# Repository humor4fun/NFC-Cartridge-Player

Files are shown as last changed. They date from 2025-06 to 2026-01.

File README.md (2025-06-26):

 # 🎞️ ESP Home Cartridge Player

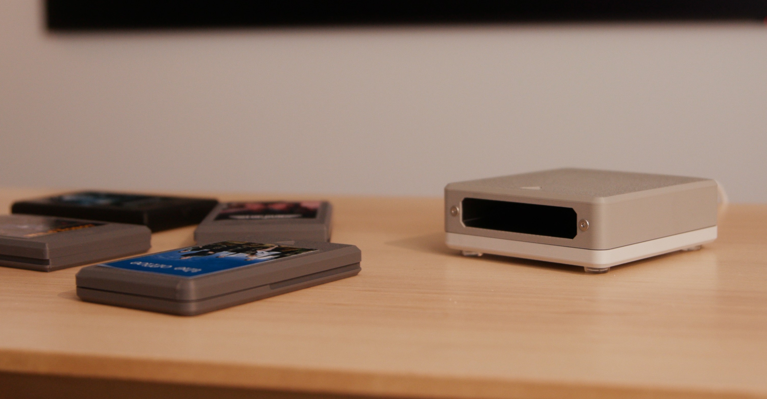
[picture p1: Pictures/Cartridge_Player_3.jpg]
Cartridge Player


Bring back the magic of movie night — without the rewinding.

This ESPHome-powered cartridge player uses NFC tags and Home Assistant to recreate the nostalgia of physical media. Insert a cartridge, and your smart home takes care of the rest: turning on the TV, playing a movie, dimming the lights — whatever you like.

Whether you're a fan of VHS-era rituals or just want a fun new way to launch automations, this project combines retro vibes with modern convenience.

---

## 🔗 Quick Links

- 🔽 **[Latest Release](https://github.com/TheStockPot/NFC-Cartridge-Player/releases/latest)**  
- 📖 **[Blog Post](https://www.thestockpot.net/videos/cartrdgeplayer)**  
- 📦 **[Bill of Materials](https://github.com/TheStockPot/NFC-Cartridge-Player/blob/TheStockPot-VideoRelease/BOM.md)**  
- 🖨️ **[3D Print Files](https://www.printables.com/model/1337649-esphome-cartridge-player)**  
- 🧠 **[ESPHome Config](https://github.com/TheStockPot/NFC-Cartridge-Player/blob/TheStockPot-VideoRelease/esphome/cartridge_player.yaml)**  
- 📺 **[Project Video](https://www.youtube.com/@TheStockPot-AU)**  
- 🛠️ **[Assembly & Automation Tutorial](https://www.youtube.com/@TheSaucepan-AU)**

---

## 🧰 What It Does

- Reads NFC tags inside custom 3D-printed cartridges  
- Sends tag ID to Home Assistant via ESPHome  
- Triggers automations like:
  - Playing a specific movie or playlist (e.g. via Plex or YouTube)
  - Turning on devices or scenes
  - Running scripts (e.g. dimming lights, launching consoles)

---

## 🛠️ Build Your Own

All components are simple and affordable, with a [Bill of Materials available here](https://github.com/TheStockPot/NFC-Cartridge-Player/blob/TheStockPot-VideoRelease/BOM.md), and a full kit available at [thestockpot.net](https://www.thestockpot.net).

🛠️ **Assembly & programming tutorial:**  
[▶️ Watch the tutorial video](https://www.youtube.com/@TheSaucepan-AU)

---

## 🧑‍💻 How It Works

1. Insert a cartridge  
2. ESP32 detects the NFC tag via the RC522  
3. ESPHome reports the tag ID to Home Assistant  
4. Home Assistant runs an automation based on the cartridge ID  
5. Cartridge removed? Media stops. Magic.

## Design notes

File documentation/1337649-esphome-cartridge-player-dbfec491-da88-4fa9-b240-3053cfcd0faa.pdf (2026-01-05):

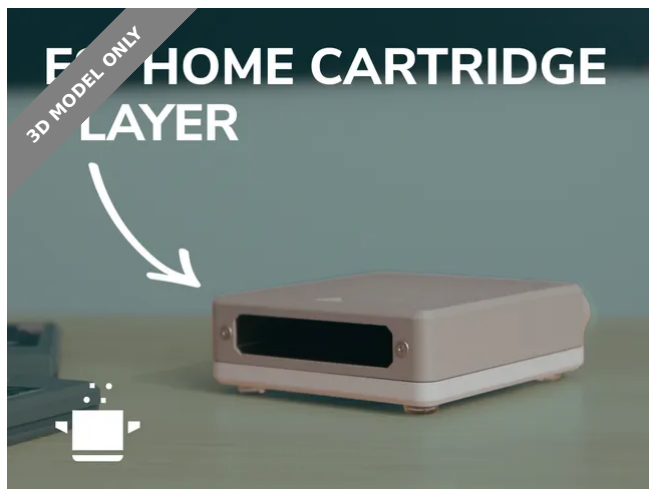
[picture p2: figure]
3D MODEL ONLY

## Summary

A little ESPHome device to stoke my physical media nostalgia!

Gadgets (https://printables.com/model?categoryId=21) > Other Gadgets (https://printables.com/model?categoryId=43)

Tags: | esp32 | homeassistant

Bring back the magic of movie night — without the rewinding.

This NFC-powered media player uses 3D-printed cartridges and ESPHome to trigger movies, playlists, or automations in Home Assistant. Just insert a cartridge, and your smart home takes care of the rest.

UPDATES 18/07/2025

Cartridge Player_Bottom_Buzzer added for use with the buzzer included in the parts kit from our website Cartridge_Top_RecessedLabel added for recessed labels (requires support) - Inspired by Bas van der Ploeg @bvdp
Clearance for cartridges slightly increased for pocket and Player_Top components

BUY A PARTS KIT HERE (https://www.thestockpot.net/store/p/cartridge-player) Links

Blog post & build guide (https://www.thestockpot.net/videos/cartrdgeplayer)

The Stock Pot (https://printables.com/@TheStockPot)

## ESPHome Cartridge Player

VIEW IN BROWSER (https://printables.com/model/1337649-esphome-cartridge-player)

updated 18. 7. 2025 | published 18. 7. 2025

•

•

•

•

GitHub repo (firmware, wiring, YAML) (https://github.com/TheStockPot/NFC-Cartridge-Player) ESPHome config (https://github.com/TheStockPot/NFC-Cartridge-Player/blob/main/YAML/ESPHome%20V1.0.2)
Bill of Materials (https://github.com/TheStockPot/NFC-Cartridge-Player/blob/main/BOM.md)
Parts kit

Features

NFC cartridge-based ESP Home device
Works with ESP32, RC522, and Home Assistant Automates anything — movies, music, lighting, games Easy to print and put together

Tutorial Video What You’ll Need

ESP32-S3 Zero
RC522 NFC module
NFC stickers (one per cartridge) Hardware
Optional: buzzer for sound feedback

Full BOM, firmware, and config available here (https://github.com/TheStockPot/NFC-Cartridge-Player)

Print Instructions

All parts should be oriented correctly when you import them into your slicer. Pictured player was printed in Bambulab Light Gray (10104) & Gray (10103)
Filament choice shouldn't matter. I've tested PETG, ABS and PLA without issue.

Cartridges:

Print with outside faces on the print bed
No supports required
Insert NFC tag before snapping halves together

There are cutting and printing templates below for printing your own labels.

Player Housing:

Use painted supports for the latch on the ‘Cartridge Player_Pocket’ component, and on the cartridge opening on the ‘Cartridge Player_Top’ component.
Avoid auto supports (bridging is intentional)

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
## Model files

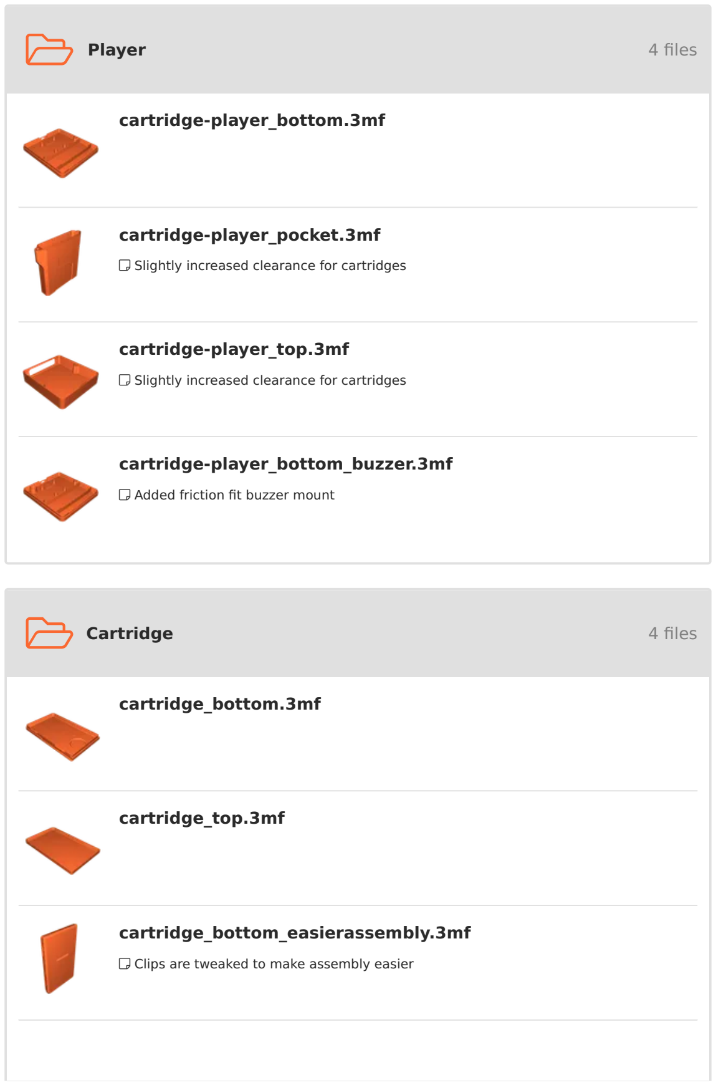
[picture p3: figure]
Player; 4 files; Added friction fit buzzer mount; Cartridge; cartridge-player_bottom.3mf; cartridge-player_pocket.3mf; cartridge-player_top.3mf; cartridge-player_bottom_buzzer.3mf; cartridge_bottom.3mf; cartridge_top.3mf; cartridge_bottom_easierassembly.3mf

- Slightly increased clearance for cartridges
- Slightly increased clearance for cartridges
- Clips are tweaked to make assembly easier

## Other files

- Label is recessed - requires support (Inspired by Bas van der Ploeg @bvdp)
- Cartridge sticker cutting template
- Cartridge sticker pdf template

## License

This work is licensed under a
Creative Commons (4.0 International License)

Attribution-NonCommercial (http://creativecommons.org/licenses/by-nc/4.0/)

✖ | Sharing without ATTRIBUTION
✔ | Remix Culture allowed
✖ | Commercial Use
✖ | Free Cultural Works
✖ | Meets Open Definition

cartridge_top_recessedlabel.3mf

sticker_template.dxf

sticker_template.pdf

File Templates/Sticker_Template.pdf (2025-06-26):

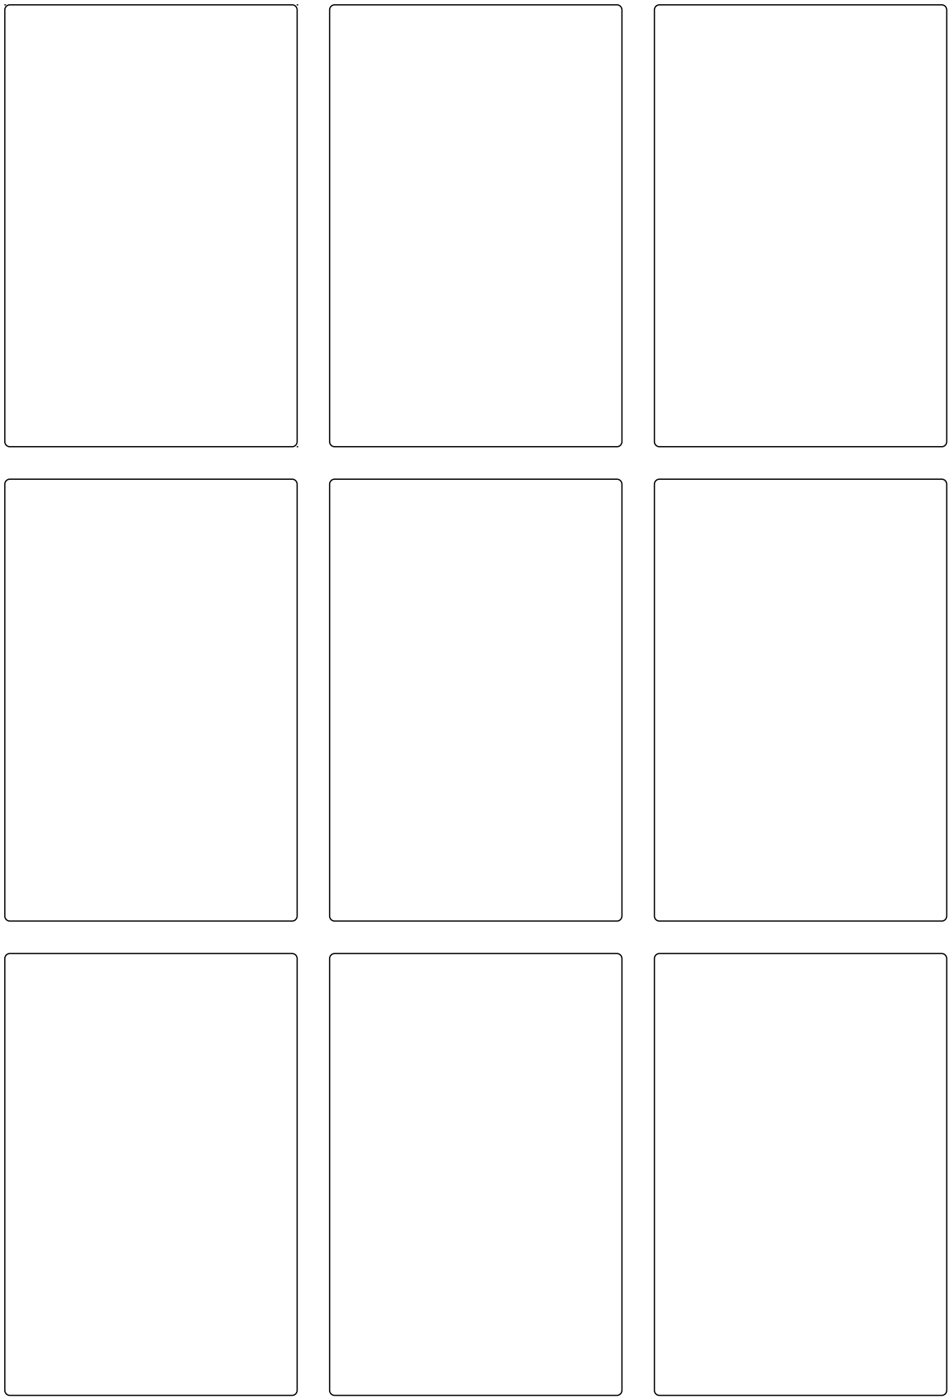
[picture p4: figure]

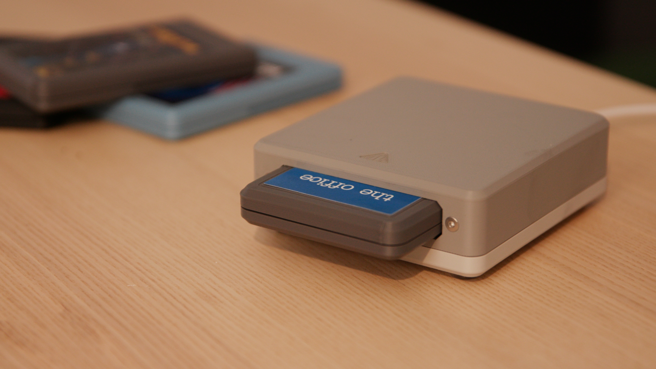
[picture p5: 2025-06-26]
Pictures/Cartridge_Player_2.jpg

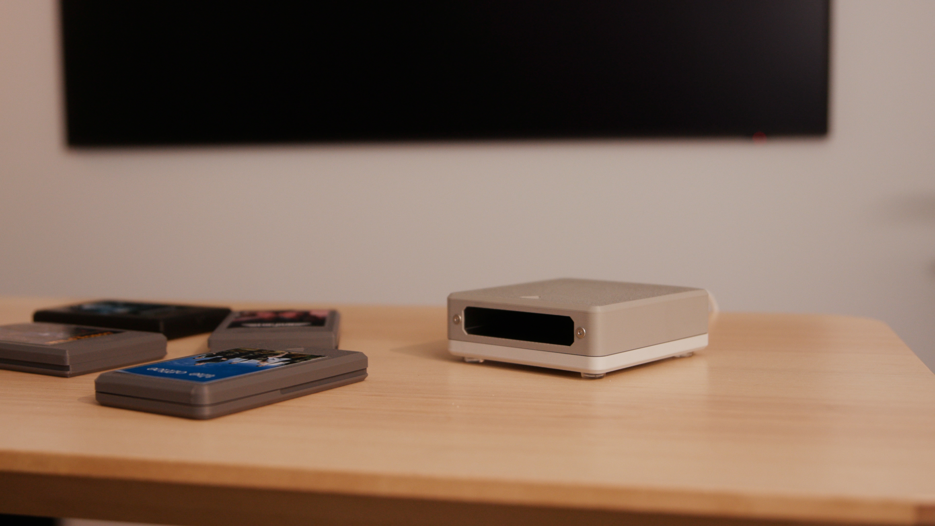
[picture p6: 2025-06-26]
Pictures/Cartridge_Player_1.jpg

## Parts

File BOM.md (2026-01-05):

# NFC Cartridge Player – Bill of Materials

Everything you need to build **The NFC Cartridge Player**.

---

## Components

| Item | Qty | Source | Notes |
|---|-----|---|---|
| ESP32-C3 Zero Dev board | 1 | [Waveshare](https://www.waveshare.com/esp32-c3-zero.html) | You can get these elswhere cheaper sometimes, the S3 model also works (use the S3 binary file) |
| RC522 RFID dev board | 1 | [Digikey](https://www.digikey.com.au/en/products/detail/sunfounder/CN0090/18668629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) | You can also get these elswhere for less. Just make sure the hole positions look the same. |
| Buzzer | 1 (optional) | [Amazon AU](https://www.amazon.com.au/QMseller-Active-Industrial-Electric-Alarmer/dp/B08G518BHN) | These are most similar to mine. They cannot be any wider than these. Smaller is fine. |
| 25mm NFC Stickers | 1 for each cartridge | [Amazon AU](https://www.amazon.com.au/50PCS-Ntag215-Enabled-Phones-Compatible/dp/B099X5TZPW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) | Almost any type will work |
| Double-sided mounting tape | 1 | | Any general-purpose double-sided tape will do. |
| Hookup Wire | 1 | | Hookup wire - 6 x 50mm lengths |
| M3 x 10mm countersunk machine screws  | 2 |  | Part of M2 screw assortments — handy to have. |
| M3 x 10mm cap head screws (pan head is ok too)  | 4 |  | Also from typical M2 screw kits. |
| 10-13mm rubber feet  | 4 |  | Standard rubber furniture feet. Available at hardware stores / online |

Alternative links and components
| Alternate | qty | Replaces what? | Source | Notes |
|---|-----|---|---|---|
| ESP32-C3 SuperMini dev board | 1 | esp32-c3 zero | [Amazon USA](https://www.amazon.com/dp/B0D47G24W3) | |
| Mifare RC522 Reader | 1 | RC522 | [Amazon USA](https://www.amazon.com/dp/B09P5WJWLN) | |
| Buzzer | 1 | Buzzer | [Amazon USA](https://www.amazon.com/dp/B0FNMH6QH8) | Note: this will NOT fit the buzzer 3dprinted buzzer holder, but will fit inside the shell if stood on its side. |
| ESP32-S3 Mini Dev Board | 1 | esp32-c3 zero | [Amazon USA](https://www.amazon.com/dp/B0CHYHGYRH) | |
| NFC Sticker | 1/cart | NFC Sticker | [Amazon USA](https://www.amazon.com/dp/B0F24L4GDM) | |
---

## 3D Prints

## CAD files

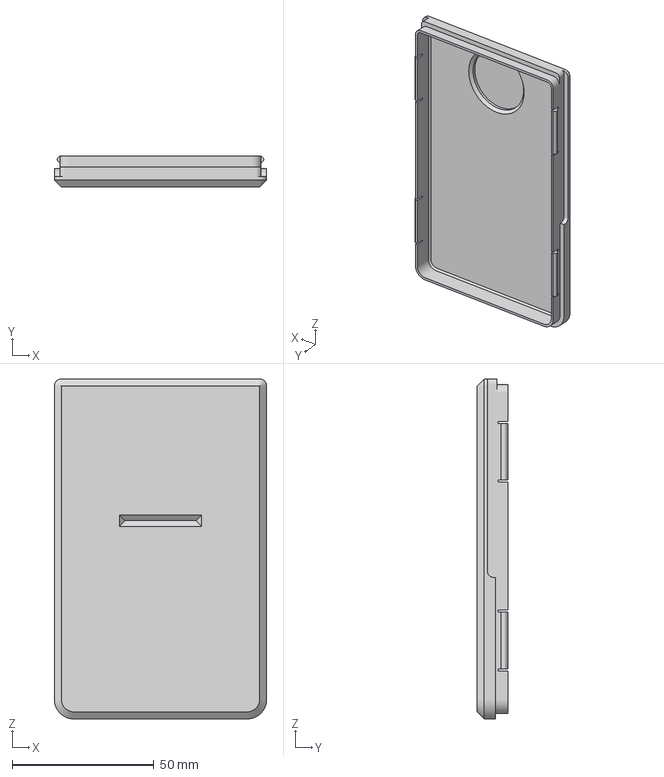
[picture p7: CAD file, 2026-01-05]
3d print files/Cartridge/cartridge_bottom_easierassembly.3mf
75.0 x 11.0 x 120.0 mm

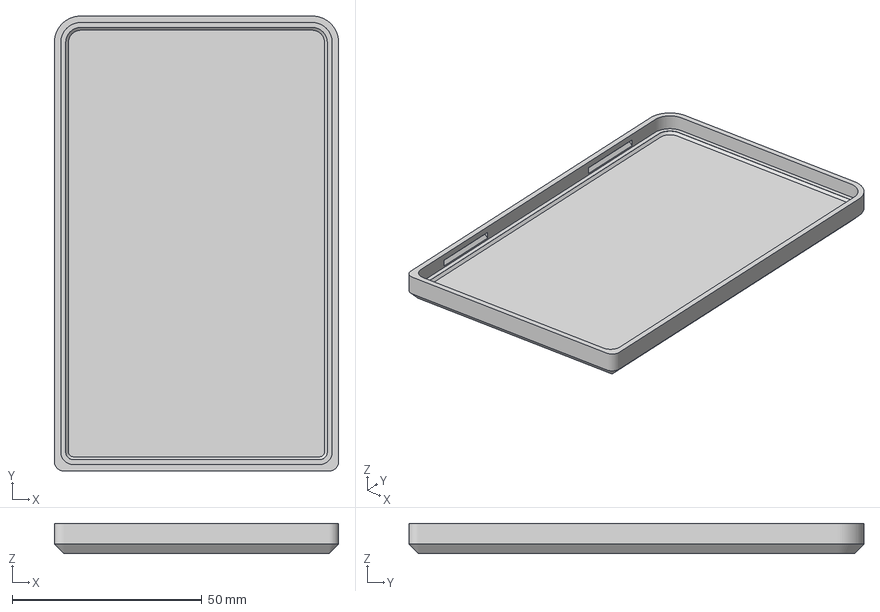
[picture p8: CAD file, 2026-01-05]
3d print files/Cartridge/cartridge_top.3mf
75.0 x 120.0 x 8.00 mm

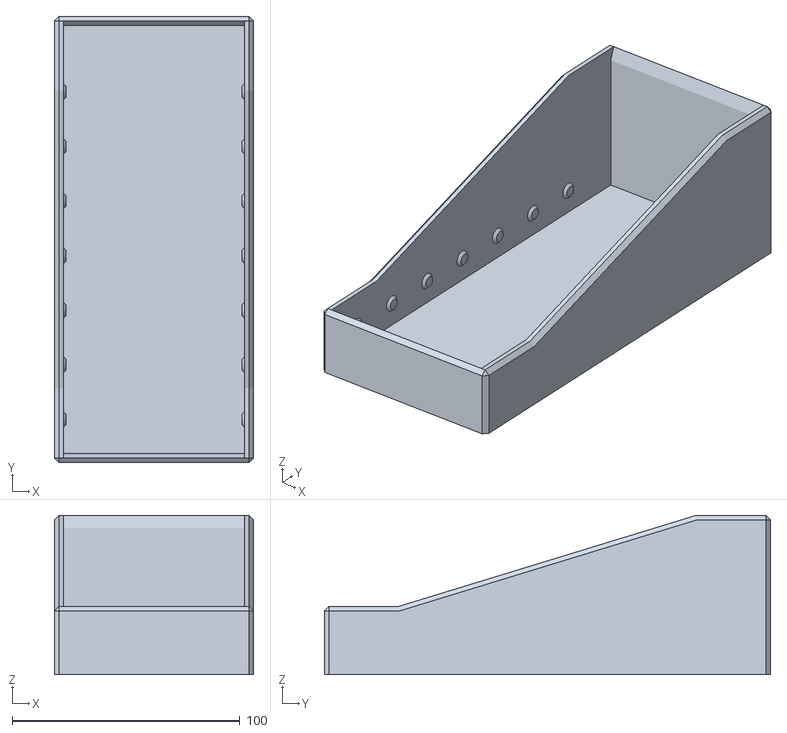
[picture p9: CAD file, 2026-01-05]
3d print files/Flip cartridge box/Box/cartridge-box-7-slot.stl
87.6 x 196.0 x 70.0

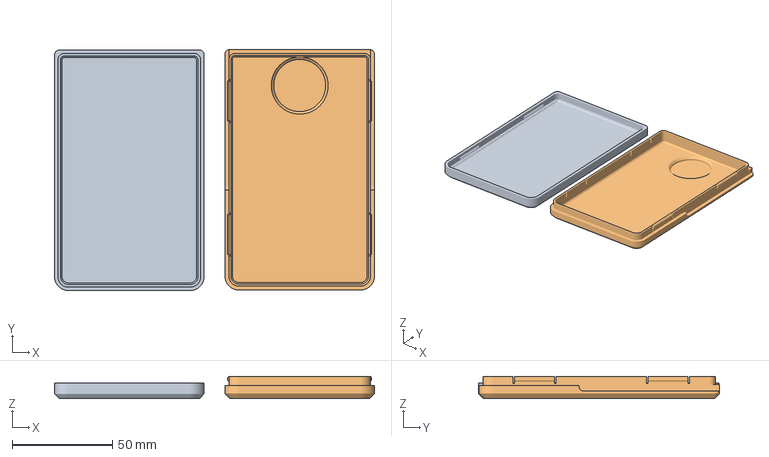
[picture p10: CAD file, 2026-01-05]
3d print files/Flip cartridge box/Cartridge/Cartridge+Modified+(Multicolor).3mf
159.6 x 120.2 x 11.0 mm
Top Case
Bottom Case

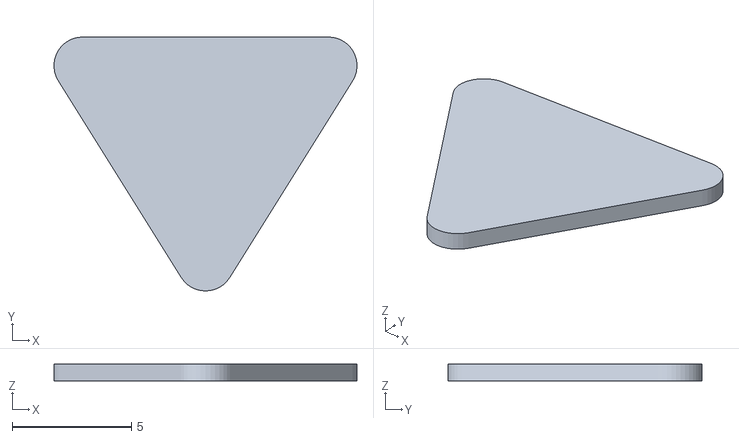
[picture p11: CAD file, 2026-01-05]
3d print files/mods/arrow insert/Triangle 0.1mm offset smaller.stl
12.7 x 10.6 x 0.7

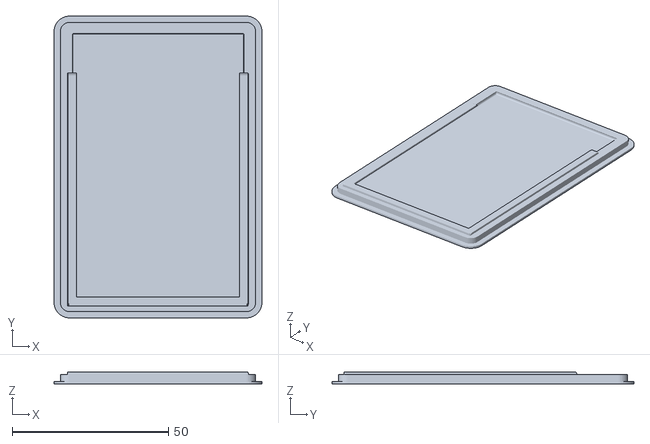
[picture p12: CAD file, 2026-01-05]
3d print files/mods/Cartridge-Card-Pouch.stl
66.5 x 96.5 x 3.80

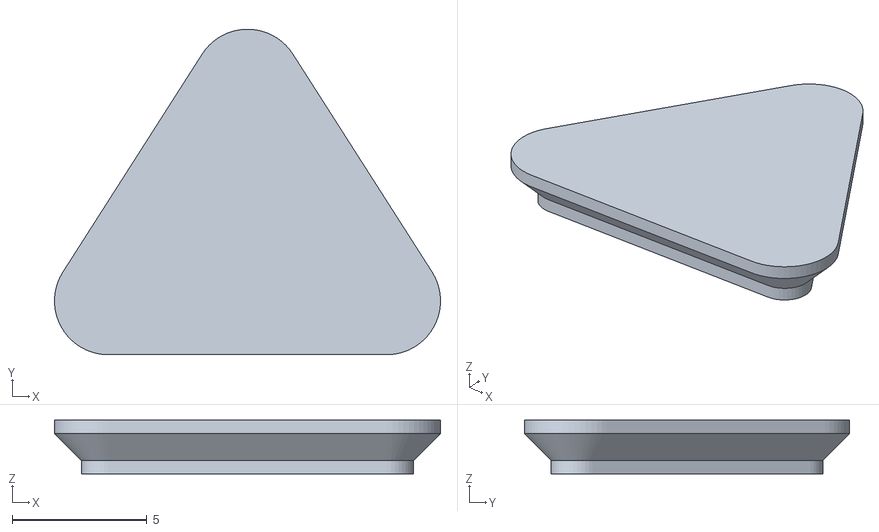
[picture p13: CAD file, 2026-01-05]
3d print files/mods/multi-part-cartridge/cartridge-arrow.stl
14.3 x 12.1 x 2.00

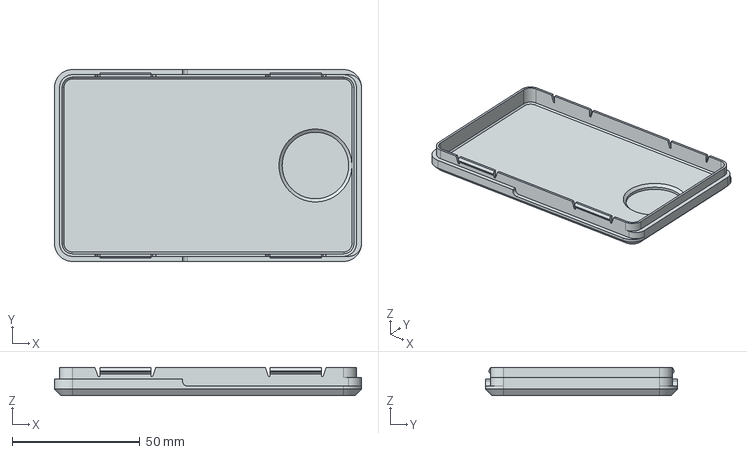
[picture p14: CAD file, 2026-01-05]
3d print files/mods/step-recreation-for-remixes/Cartridge Alterations/cartbottom_custclips_equalcorners.stp
120.0 x 75.0 x 11.0 mm

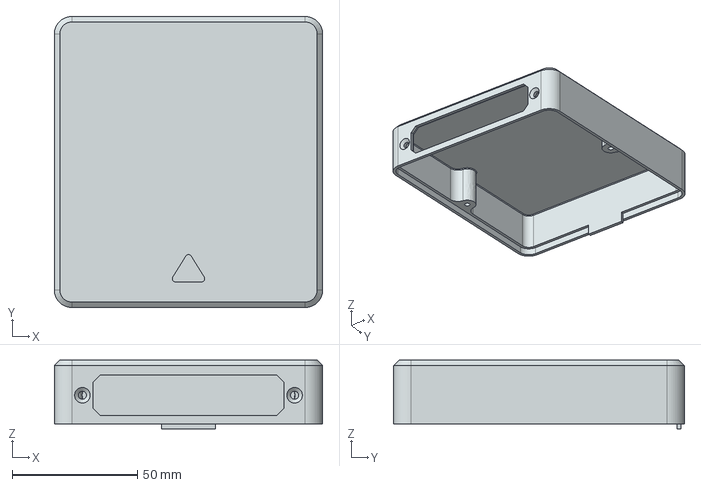
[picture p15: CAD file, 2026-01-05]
3d print files/mods/step-recreation-for-remixes/STEPRecreations/playertopv2_steprecreation.stp
107.0 x 116.0 x 27.4 mm

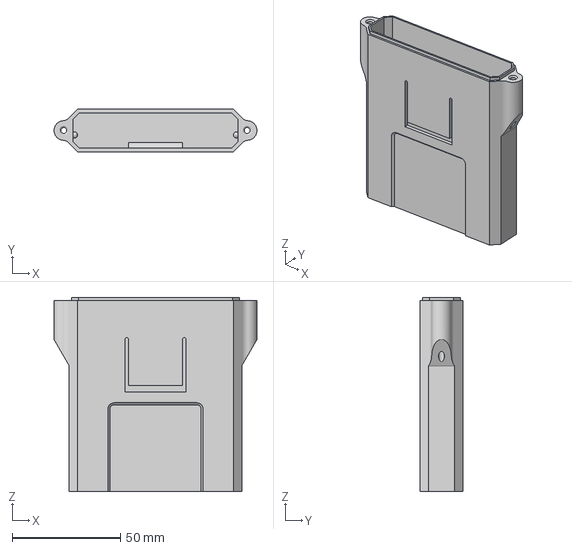
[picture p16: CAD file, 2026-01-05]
3d print files/Player/cartridge-player_pocket.3mf
93.6 x 19.6 x 89.5 mm

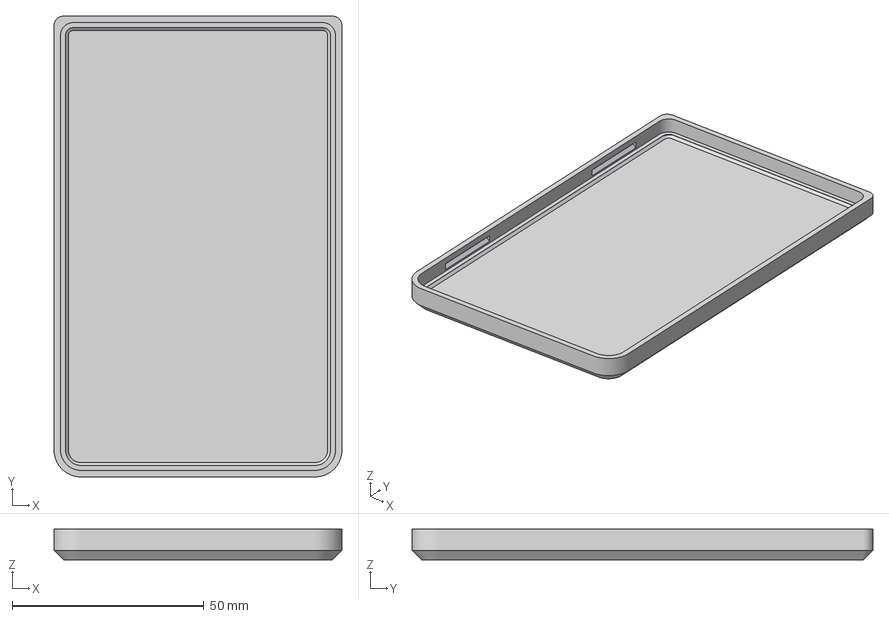
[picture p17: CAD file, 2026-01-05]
3d print files/Cartridge/cartridge_top_recessedlabel.3mf
75.0 x 120.0 x 8.00 mm

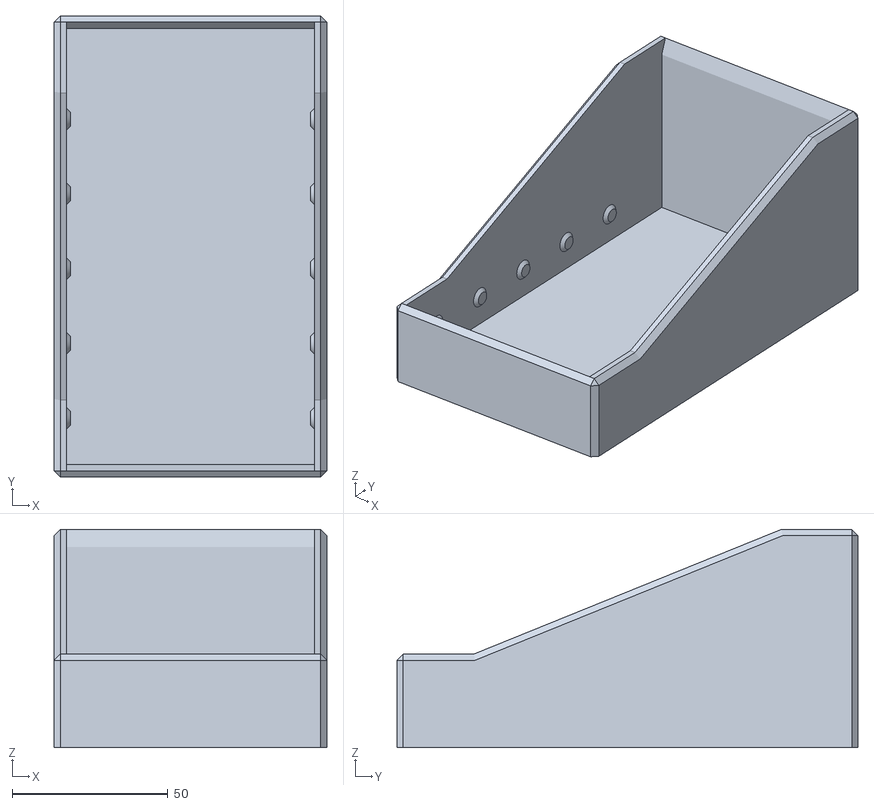
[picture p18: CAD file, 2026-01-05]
3d print files/Flip cartridge box/Box/cartridge-box-5-slot.stl
87.6 x 148.0 x 70.0

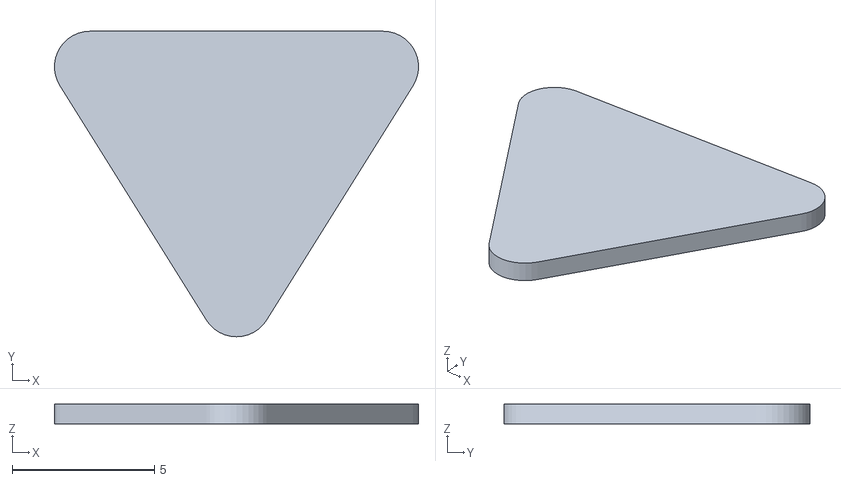
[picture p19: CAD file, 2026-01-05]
3d print files/mods/arrow insert/Triangle 0.05mm smaller.stl
12.8 x 10.7 x 0.7

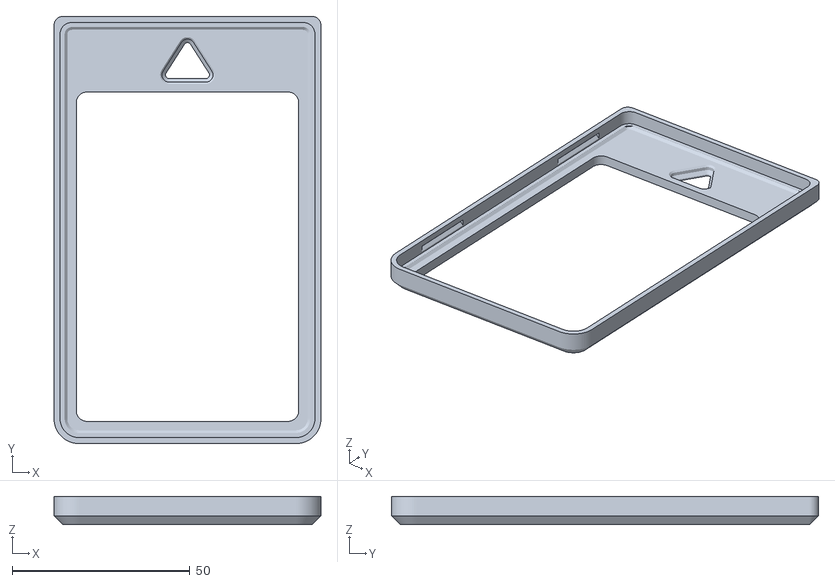
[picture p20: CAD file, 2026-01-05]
3d print files/mods/multi-part-cartridge/cartridge-top.stl
75.0 x 120.0 x 8.00

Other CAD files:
3d print files/mods/multi-part-cartridge/cartridge-bottom_easierassembly.stl
Templates/Sticker_Template.dxf
3d print files/Flip cartridge box/Cartridge/Cartridge+Bottom.stl
3d print files/mods/step-recreation-for-remixes/Cartridge Alterations/cartbottom_bluntclips_equalcorners.stp
3d print files/Cartridge/cartridge_bottom.3mf
3d print files/Flip cartridge box/Box/cartridge-box-10-slot.stl
3d print files/Flip cartridge box/Box/cartridge-box-3-slot.stl
3d print files/Flip cartridge box/Box/cartridge-box-4-slot.stl
3d print files/Flip cartridge box/Box/cartridge-box-6-slot.stl
3d print files/Flip cartridge box/Box/cartridge-box-8-slot.stl
3d print files/Flip cartridge box/Box/cartridge-box-9-slot.stl
3d print files/Flip cartridge box/Box/cartridge-slot.stl
3d print files/Flip cartridge box/Box/stock-pot-cartridge-player-6-slots.3mf
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

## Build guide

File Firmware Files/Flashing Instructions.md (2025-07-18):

# Flashing ESP32 with New ESPHome Firmware

Follow these steps to flash your ESP32 device with new firmware using [web.esphome.io](https://web.esphome.io):

1. Go to [web.esphome.io](https://web.esphome.io) in Google Chrome or Microsoft Edge.
2. Plug in your ESP32 device via USB.

>[!NOTE]
>If it's your first time you may be prompted to install a driver or grant permission to access the USB device. Approve any pop-ups that appear.

3. Click **Connect** and choose your ESP32 device from the list.
4. Click **Install**, then choose **"Pick a file"** and select the `.bin` firmware file from the GitHub repository.
5. Wait for the flashing process to complete. This may take up to a minute.
6. Once complete, unplug and reconnect your device.

---

### Troubleshooting

If the install fails:

- Press and hold the **BOOT** button on your ESP32.
- While holding **BOOT**, tap the **RESET** button once.
- Continue from step 3

> This puts your ESP32 into a special download mode required for flashing.

---

### Notes

- This process works best in **Google Chrome** or **Microsoft Edge**.
- If your device doesn’t show up, try a different USB cable or port.
- Make sure your `.bin` file is built for the correct ESP32 variant.

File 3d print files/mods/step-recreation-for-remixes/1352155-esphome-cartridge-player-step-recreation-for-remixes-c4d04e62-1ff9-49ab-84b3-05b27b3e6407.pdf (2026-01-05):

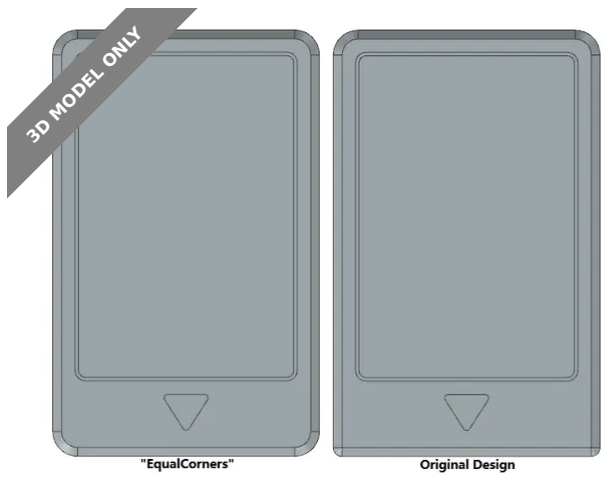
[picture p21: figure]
3D MODEL ONLY

## Summary

STEP recreations of the original files and a few versions with slight design alterations.

Gadgets (https://printables.com/model?categoryId=21) > Other Gadgets (https://printables.com/model?categoryId=43)

Tags: | esp32 | media | homeassistant

These models are recreations and alterations of The Stock Pot's (https://www.printables.com/@TheStockPot) ESPHome Cartridge Player (https://www.printables.com/model/1337649-esphome-cartridge-player) post. The main purpose for this upload is to make it easier to alter these models for the purpose of remixes. I think there could be some awesome alternate designs, especially of the player.

You can use the key below to understand what alterations have been made to each file.

UPDATE 7/28/2025:

Added STEP recreations of the player models.

Vikrael (https://printables.com/@vikrael)

## ESPHome Cartridge Player - STEP recreation for remixes

VIEW IN BROWSER (https://printables.com/model/1352155-esphome-cartridge-player-step-recreation-for-remix)

updated 31. 7. 2025 | published 31. 7. 2025

## Model files

Filename key:

STEPRecreation - Models with this in the filename are meant to be exact recreations of the original files by TheStockPot, but exported as STEP. These were made from scratch, so if anything seems off, I might have overlooked it. Please let me know and I'll fix it.

EqualCorners - Models with this in the filename have had the corner radii of the inserted edge of the cartridge altered to match the opposite corners. I was getting some warping on those corners, so this was actually done to help combat that. I also added a radius to the end of the guide slot as well.

BluntClips - Models with this in the filename have had the snapfit tabs altered to make it easier to snap them together.

CustClips - A more extreme alteration of the snapfit tabs.

MinimalBridging - Altered insert triangle to minimize bridging

## This remix is based on

ESPHome Cartridge Player (https://printables.com/model/1337649-esphome-cartridge-player)
by The Stock Pot (https://printables.com/@TheStockPot)
- STEPRecreations | 6 files

carttop_steprecreation.stp

cartbottom_steprecreation.stp

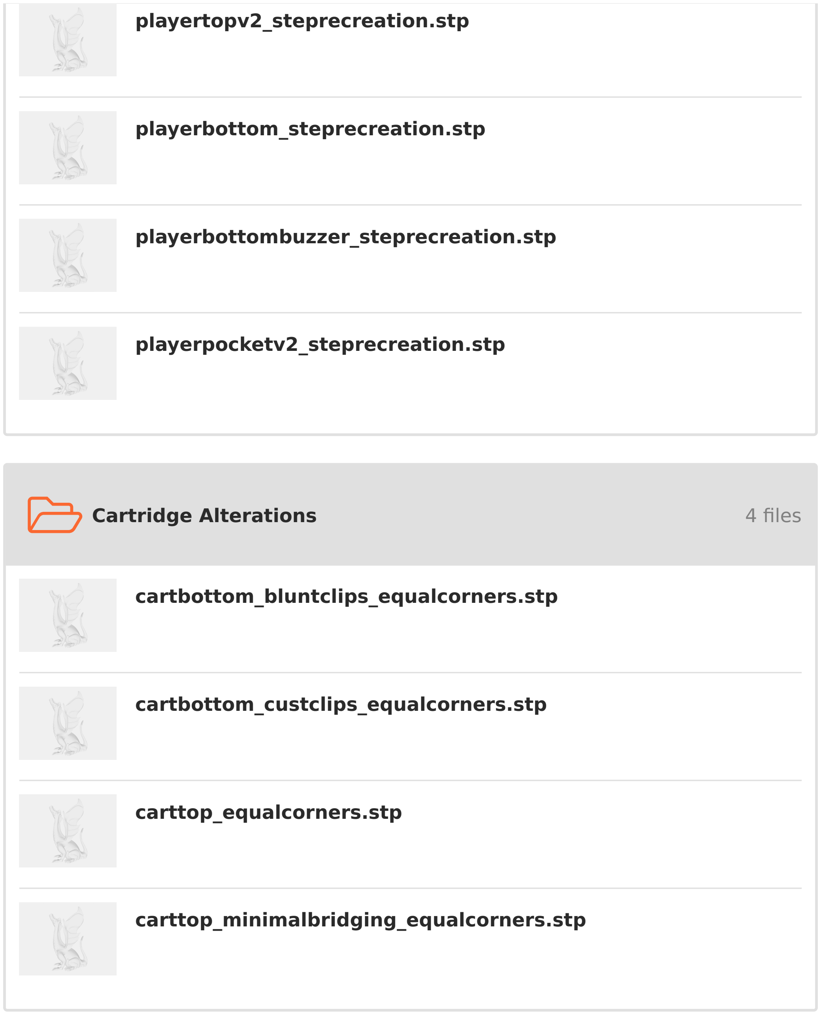
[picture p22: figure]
Cartridge Alterations; 4 files; playertopv2_steprecreation.stp; playerbottom_steprecreation.stp; playerbottombuzzer_steprecreation.stp; playerpocketv2_steprecreation.stp; cartbottom_bluntclips_equalcorners.stp; cartbottom_custclips_equalcorners.stp; carttop_equalcorners.stp; carttop_minimalbridging_equalcorners.stp

## License

This work is licensed under a
Creative Commons (4.0 International License) (http://creativecommons.org/licenses/by-nc/4.0/)

Attribution-NonCommercial (http://creativecommons.org/licenses/by-nc/4.0/)

✖ | Sharing without ATTRIBUTION
✔ | Remix Culture allowed
✖ | Commercial Use
✖ | Free Cultural Works
✖ | Meets Open Definition

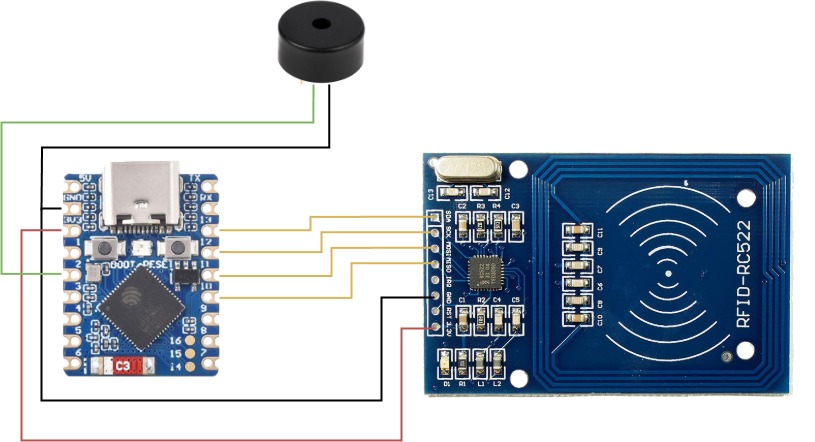
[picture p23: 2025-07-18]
Wiring Diagrams/Wiring - ESP32-S3.jpg

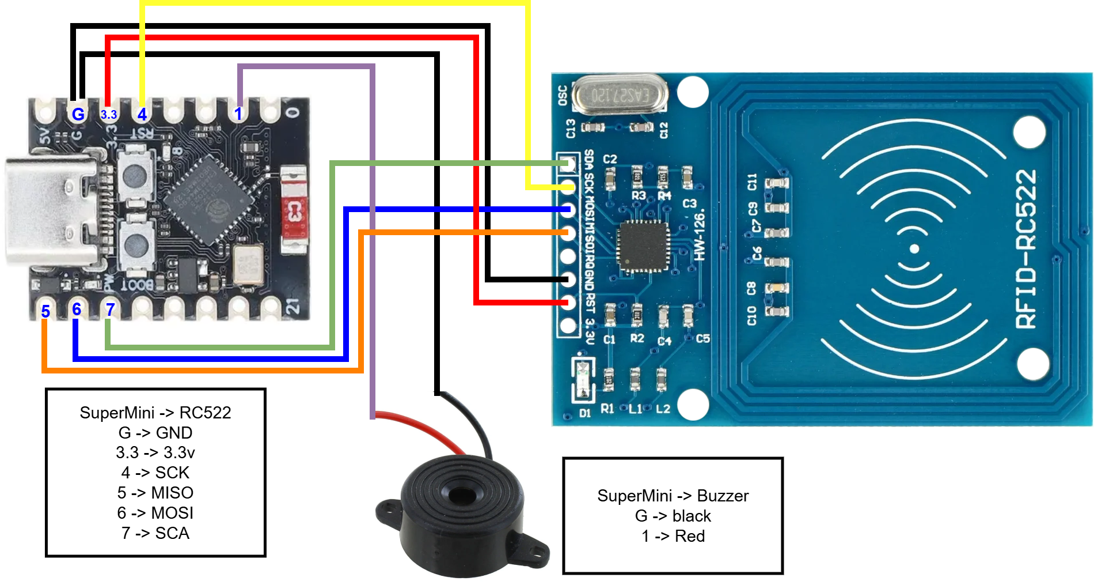
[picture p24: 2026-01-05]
Wiring Diagrams/Wiring-Diagram-esp32-c3-supermini.png

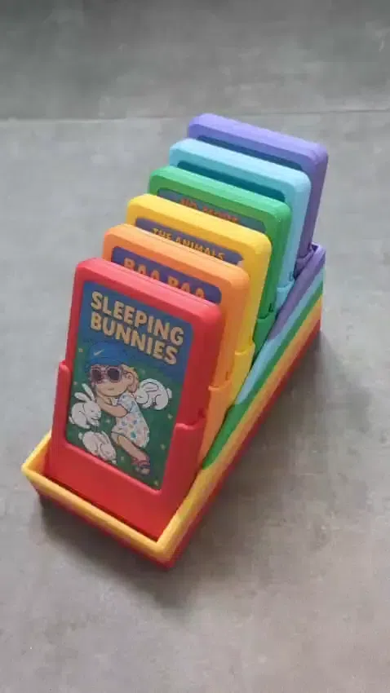
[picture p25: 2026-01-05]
3d print files/Flip cartridge box/2025-07-23_7cb173048f0598.webp

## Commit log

2025-06-25 Wiring diagram
2025-06-25 Added sticker templates
    [Sticker_Template.dxf]
2025-06-25 Moving templates
    [Sticker_Template.dxf]
2025-07-17 Rename Cartridge Player Wiring.png to Wiring Diagrams
2025-07-17 Rename ESPHome V1.0.2 to ESPHome YAML V1.0.2 - ESP32-S3
2025-07-17 Rename ESPHome YAML V1.0.2 - ESP32-S3 to ESPHome YAML - ESP32-S3
2025-07-17 Create ESPHome YAML - ESP32-C3
2025-07-18 Update ESPHome YAML - ESP32-C3
2026-01-05 support for c3-supermini
    - purchase links for US BOM from amazon
    - c3-supermini:
    - wiring diagram
    - wiring photos
    - board photos
    - binary firmware
    - yaml
    - template for wiring diagram
    - code in the yaml for buzzer beep codes to indicate activity is happening (boot, wifi connect, tag insert, tag remove)
2026-01-05 added model files
    [Cartridge+Bottom.stl, Cartridge+Modified+(Multicolor).3mf, Cartridge+Top.stl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]
